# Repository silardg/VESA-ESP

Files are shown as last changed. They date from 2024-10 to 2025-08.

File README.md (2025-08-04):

# VESA-Mountable ESP32-S3 with VGA Output

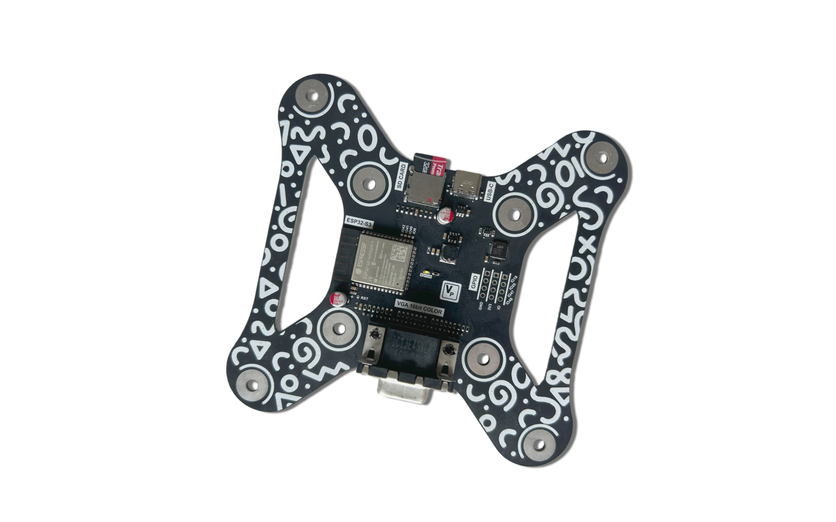
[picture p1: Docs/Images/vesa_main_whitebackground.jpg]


## Overview

This project is a **VESA-mountable ESP32-S3** development board with **VGA output** — a unique and space-saving solution for embedded applications that benefit from graphical displays.

The core idea is simple: create a **microcontroller-based VGA device** that can be easily attached to the back of a monitor using a **VESA-compatible plate PCB**. This results in a clutter-free and elegant hardware setup, ideal for DIYers, educators, and tinkerers.

## Why It’s Cool

- **VGA from a microcontroller**: VGA video from the ESP32-S3 is no small feat.
- **Compact design**: Mounts directly behind your monitor using standard VESA mounting holes.
- **Open Hardware**: Schematics and PCB designs are fully available.

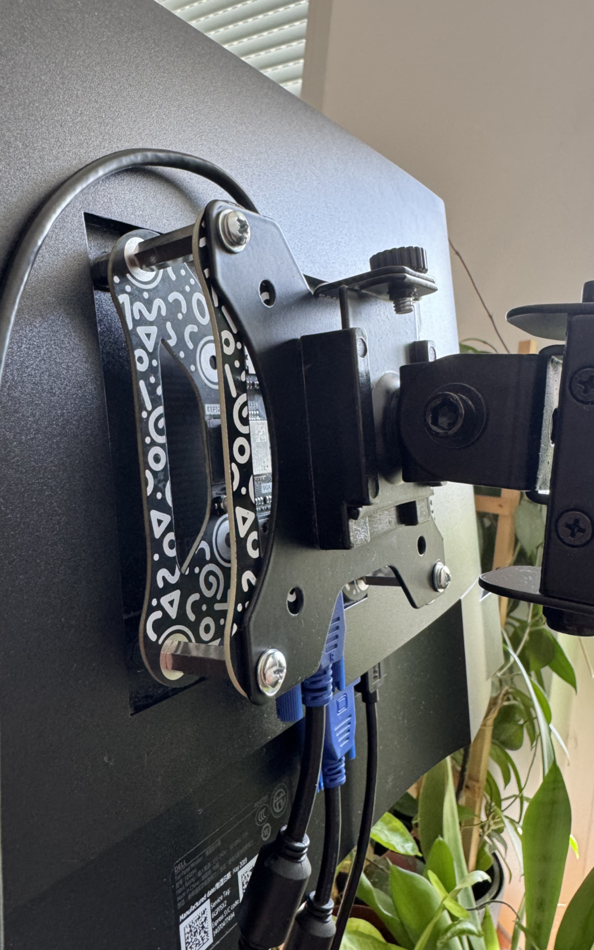
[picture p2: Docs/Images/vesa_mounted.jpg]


## Shoutout

This project wouldn’t be possible without the incredible work of **[BitLuni](https://github.com/bitluni)**, who developed the groundbreaking library that enables VGA output on the ESP32-S3.

## Project Files

The GitHub repository contains:

- ✅ Schematic files  
- ✅ PCB layout files  
- ✅ Firmware

## Documentation
The documentation can be found [here](Docs/DOC.md).

## Mechanical 
Link to the mechanical files can be found [here](Hardware/Main/Manufacturing/Assembly/Dimensions.pdf).

## Certification
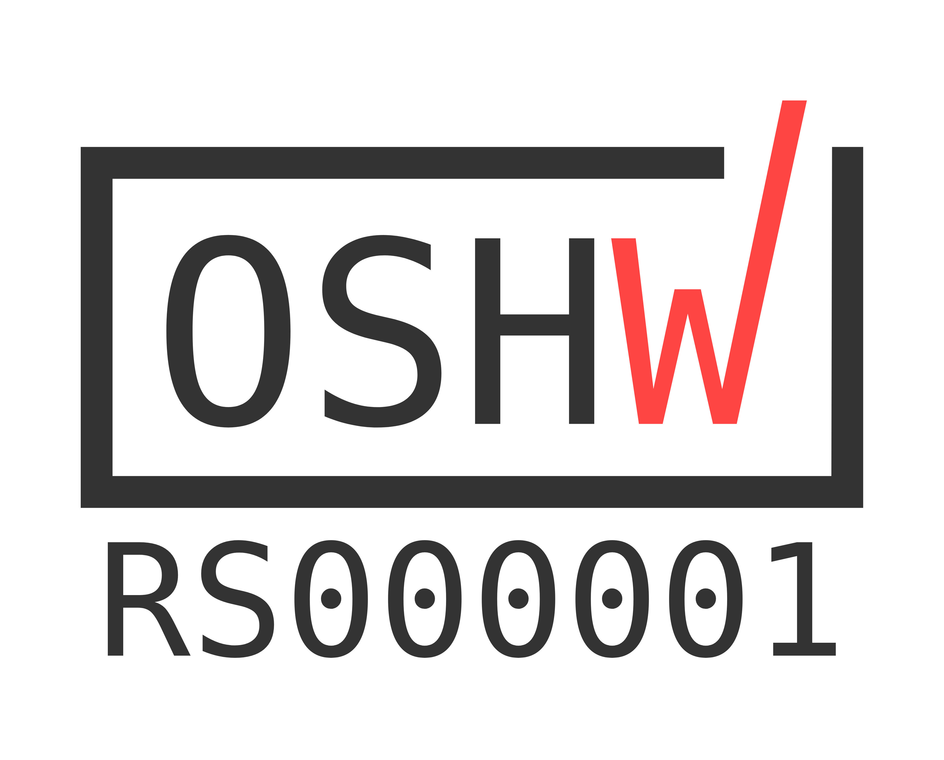
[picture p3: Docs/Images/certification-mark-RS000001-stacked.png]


You can view more [here](https://certification.oshwa.org/rs000001.html) about the certification. P.S. First OSHWA in Serbia!

## Media Coverage
- 🔗 [Official WebPage](https://silardgal.com/projects/vesaesp.html)
- 🔗 [LinkedIn Post](https://www.linkedin.com/posts/silard-gal_hobby-project-finally-finished-this-activity-7321973185086722048-SGIh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)
- 🔗 [Hackaday.io Project Page](https://hackaday.io/project/203136-vesa-esp)
- 🔗 [Hackster.io — Gareth Halfacree’s writeup](https://www.hackster.io/news/silard-gal-s-vesa-esp-puts-an-espressif-esp32-s3-on-the-back-of-any-vesa-compatible-display-0b7a13a0985f)
- More coverage coming soon!

## Licenses


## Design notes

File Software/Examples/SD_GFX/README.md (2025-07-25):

# SD_GFX.ino

## Overview
This Arduino sketch combines SD card access with VGA display output on an ESP32-S3 microcontroller using the VESA-ESP. It lists the contents of an SD card on both the Serial Monitor and a VGA display using the `ESP32S3VGA` and `Adafruit_GFX` libraries.

## Functionality
- **SPI Setup**: Configures a custom SPI interface for SD card communication using defined pins for MOSI, MISO, SCK, and CS.
- **SD Card Initialization**: Initializes the SD card using the `SD` library.
- **Display Setup**: Initializes a VGA display in 320x240 resolution at 60Hz using the `ESP32S3VGA` library.
- **Directory Listing**: Recursively lists all files and directories on the SD card, printing their names to the Serial Monitor and displaying them on the VGA screen with a 200ms delay between each entry.
- **Static Operation**: The listing occurs once during setup, with no actions in the loop.

## Required Libraries
- **ESP32S3VGA**: Provides VGA output functionality for the ESP32-S3.
- **Adafruit_GFX**: A graphics library used via `GfxWrapper` for rendering text and shapes.
- **Adafruit_BusIO** (dependency for Adafruit_GFX): Handles I2C/SPI communication.
- **SD**: Standard Arduino library for SD card operations.
- **SPI**: Standard Arduino library for SPI communication.

## Library Installation
1. Open the Arduino IDE.
2. Go to **Sketch > Include Library > Manage Libraries**.
3. Search for and install:
   - **Adafruit_GFX** (installs Adafruit_BusIO automatically).
   - **SD** and **SPI** (typically included with the Arduino core for ESP32).
4. For **ESP32S3VGA**, refer to the main README for detailed installation instructions, as it may require downloading from an external repository (e.g., GitHub, if provided by the author, such as bitluni) and placing it in the Arduino `libraries` directory or adding it as a `.zip` file.
5. Restart the Arduino IDE after installation.

## Notes
- A VGA connection is needed for the VESA-ESP to display the output.

## Usage
1. Connect an SD card module and ensure the VESA-ESP is connected to a VGA monitor.
2. Insert an SD card formatted with a FAT32 or exFAT file system.
3. Upload the sketch to the ESP32-S3 using the Arduino IDE.
4. Open the Serial Monitor (115200 baud) to view the SD card's directory listing.
5. The VGA monitor will display each file/directory name with a 200ms delay between entries.

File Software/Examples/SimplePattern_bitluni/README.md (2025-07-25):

# SimplePattern_bitluni.ino

## Overview
This Arduino sketch demonstrates a simple VGA display pattern for the ESP32-S3 microcontroller using the VESA-ESP. It generates a colorful test pattern on a VGA monitor using the `ESP32S3VGA` library.

## Functionality
- **Display Setup**: Initializes a VGA display in 800x600 resolution at 60Hz (with an option for 1024x768 commented out).
- **Pattern Generation**: Creates a gradient pattern across the screen where pixel colors are based on their x and y coordinates.
- **Color Bars**: Draws three horizontal color bars (red, green, blue) at the top of the screen, each 30 pixels high, with intensity varying from 0 to 255.
- **Static Display**: The pattern is rendered once and displayed continuously.

## Required Libraries
- **ESP32S3VGA**: Provides VGA output functionality for the ESP32-S3.

## Library Installation
1. Open the Arduino IDE.
2. For **ESP32S3VGA**, refer to the main README for detailed installation instructions, as it may require downloading from an external repository (e.g., GitHub, if provided by the author, such as bitluni) and placing it in the Arduino `libraries` directory or adding it as a `.zip` file.
3. Restart the Arduino IDE after installation.

## Notes
- A VGA connection is needed for the VESA-ESP to display the output.

## Usage
1. Ensure the VESA-ESP is connected to a VGA monitor.
2. Upload the sketch to the ESP32-S3 using the Arduino IDE.
3. The VGA monitor will display the gradient pattern and color bars.

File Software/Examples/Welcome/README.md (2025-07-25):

# Welcome.ino

## Overview
This Arduino sketch is designed for the ESP32-S3 microcontroller to display a thank-you message and a QR code on a VGA monitor using the VESA-ESP. It uses the `ESP32S3VGA` library to interface with a VGA display and the `GfxWrapper` library to render text and graphics.

## Functionality
- **Display Setup**: Initializes a VGA display in 320x240 resolution at 60Hz using the `ESP32S3VGA` library.
- **Text Rendering**: Displays the text "Thank you!" and "For supporting this project! More on:" using the `FreeSerif24pt7b` font.
- **QR Code Rendering**: Renders a 100x100 pixel QR code from a predefined `qr_map` array, where each pixel is either black (1) or white (0).
- **Continuous Display**: The display is updated once and then holds indefinitely with a 500ms delay loop.

## Required Libraries
- **ESP32S3VGA**: Provides VGA output functionality for the ESP32-S3.
- **Adafruit_GFX**: A graphics library used via `GfxWrapper` for rendering text and shapes.
- **Adafruit_BusIO** (dependency for Adafruit_GFX): Handles I2C/SPI communication.

## Library Installation
1. Open the Arduino IDE.
2. Go to **Sketch > Include Library > Manage Libraries**.
3. Search for and install:
   - **Adafruit_GFX** (installs Adafruit_BusIO automatically).
4. For **ESP32S3VGA**, refer to the main README for detailed installation instructions, as it may require downloading from an external repository (e.g., GitHub, if provided by the author, such as bitluni) and placing it in the Arduino `libraries` directory or adding it as a `.zip` file.
5. Restart the Arduino IDE after installation.

## Notes
- A VGA connection is needed for the VESA-ESP to display the output.

## Usage
1. Ensure the VESA-ESP is connected to a VGA monitor.
2. Upload the sketch to the ESP32-S3 using the Arduino IDE.
3. The VGA monitor will display the thank-you message and QR code.

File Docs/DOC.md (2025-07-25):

# VESA-ESP Documentation
## Hardware
### Links
The *SCHEMATIC* can be found [here](../Hardware/Main/Manufacturing/Assembly/VESA-ESP%20([No%20Variations])%20Schematic.PDF).

The *ASSEMBLY* can be found [here](../Hardware/Main/Manufacturing/Assembly/VESA-ESP%20([No%20Variations])%20Assembly%20Drawing.PDF).

The *3D VIEW* can be found [here](../Hardware/Main/Manufacturing/Assembly/VESA-ESP%20([No%20Variations])%20PCB%203D%20Printout.PDF).

### Block Diagram
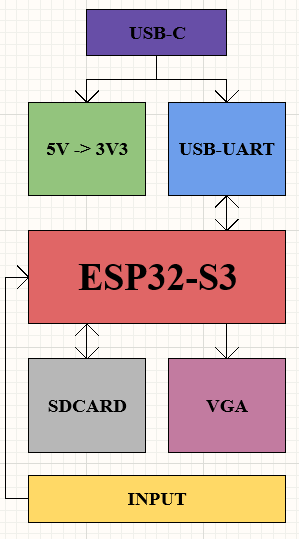
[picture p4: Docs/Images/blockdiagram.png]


### Main Parts
- ESP32-S3
- USB-UART
- VGA Connector
- USB-C and Power
- Inputs
- SD Card

### How to use it and install it?
- Step #1 VGA: Connect a VGA cable to a VGA compatible monitor/tv
- Step #2 Power: USB-C, 5V
- Step #3 Greeted by welcome message (in case the device was sourced from us, if not, follow the below instructions to flash it)
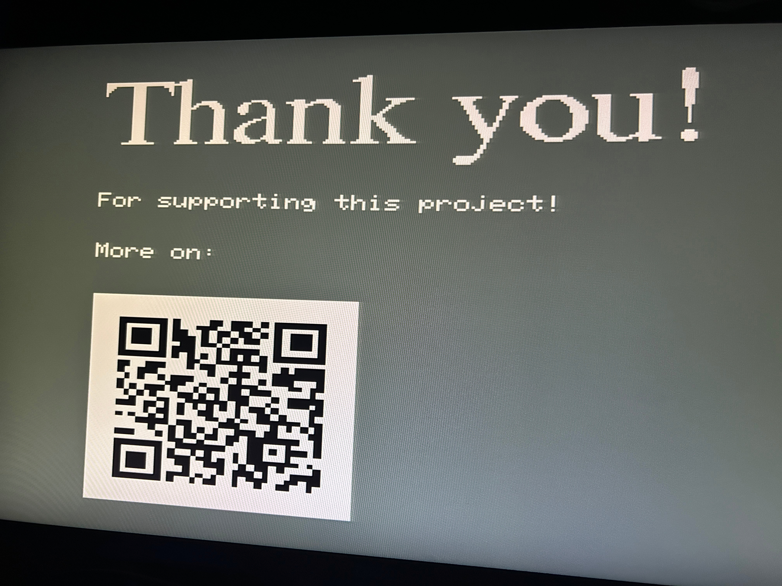
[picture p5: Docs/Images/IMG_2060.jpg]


The device is made so that it can be mounted on the back of monitors using the two groups of screws.
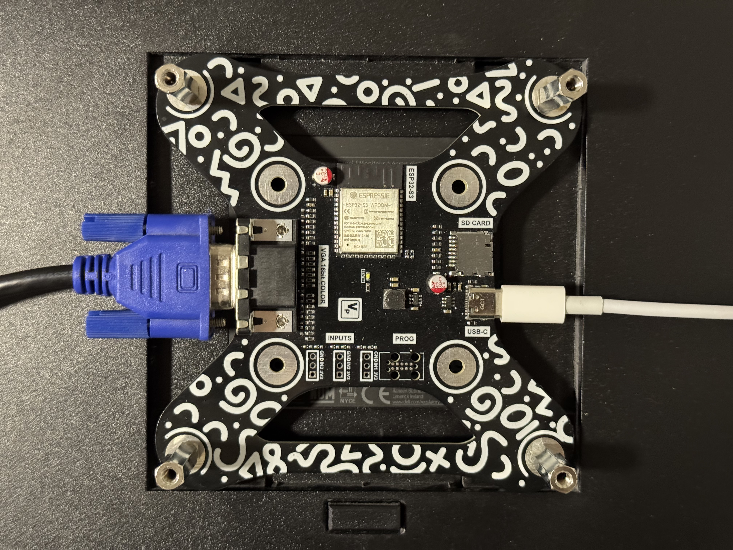
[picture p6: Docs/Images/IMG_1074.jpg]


The additional adapter plate is there to allow using stands with the device. 
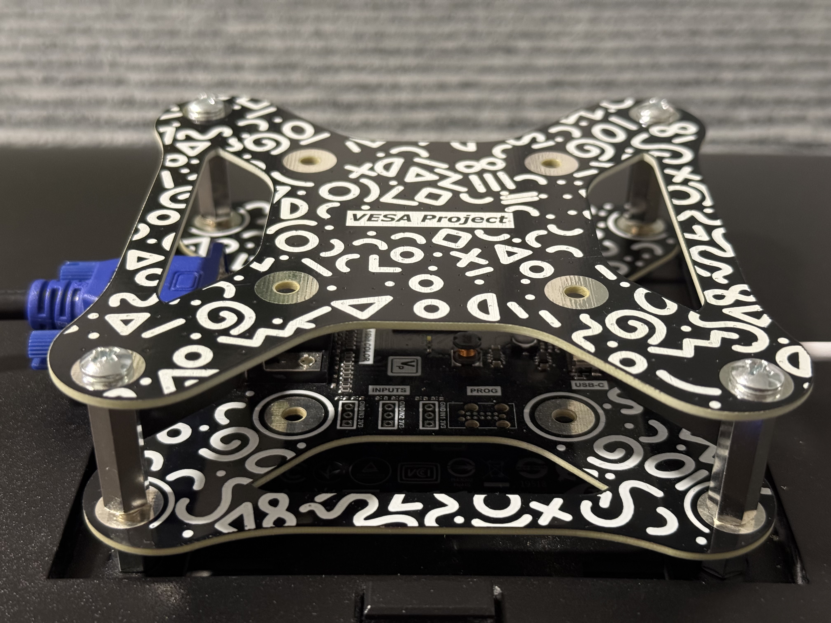
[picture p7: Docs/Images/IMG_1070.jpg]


## Software/Firmware
### Setup the software
- Step #1 Install Arduino: [Install the Arduino IDE](https://www.arduino.cc/en/software/)
- Step #2 Install ESP32: Add https://dl.espressif.com/dl/package_esp32_index.json to the Boards Manager URL in the Preferences ( File -> Preferences)
- Step #3 Install bitluni library: [Intro here](https://github.com/bitluni/ESP32Lib)
- Step #4 Run bitluni or our Examples!
### VGA Output
The VGA output is the main purpose of this device, meaning all examples are using it!

The device should come with a pre-loaded firmware that will showcase some text, thanking for support and a QR code leading to this webpage.

In the [Software/Examples](../Software/Examples/) section there are many examples to get started from. 
### SD Card Interfacing
The example [SD_Test](../Software/Examples/SD_Test/) and [SD_GFX](../Software/Examples/SD_GFX/) is used to showcase the SD Card. 

As shown on the schematic, only 1-bit mode is used to interface the SD-Card, because of the limitation of the ESP32 with OPI PSRAM.
### GPIO interfacing
IO19, IO20, IO47 and IO48 can be used as separate IO on the connector. 

### Licenses


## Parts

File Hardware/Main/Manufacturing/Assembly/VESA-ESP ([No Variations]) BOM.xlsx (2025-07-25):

Name | Description | Designator | LibRef | Quantity | Layer | MPN
3.9uH/3.6A | FIXED IND 3.9UH 3.6A 65 MOHM SMD | L1 | 3.9uH/3.6A | 1 | Top | SDE0604A-3R9M
5K1 1% | 5.1 kOhms ±1% 0.1W, 1/10W Chip Resistor 0603 (1608 Metric) Automotive AEC-Q200 Thick Film | R1, R2 | 5K1 1% | 2 | Top | ERJ-3EKF5101V
22uF 6V3 | 22 µF ±20% 6.3V Ceramic Capacitor X5R 0603 (1608 Metric) | C2, C5, C6, C7, C10 | 22uF 6V3 | 5 | Top | GRM188R60J226MEA0D
150R 1% | 150 Ohms ±1% 0.1W, 1/10W Chip Resistor 0603 (1608 Metric) Automotive AEC-Q200 Thick Film | R9, R10, R11, R12, R14, R22, R23, R24, R25, R33, R34, R35, R36, R38, R46 | 150R 1% | 15 | Top | ERJ-3EKF1500V
300R 1% | 300 Ohms ±1% 0.1W, 1/10W Chip Resistor 0603 (1608 Metric) Automotive AEC-Q200 Thick Film | R3, R4, R5, R6, R7, R13, R16, R17, R18, R19, R20, R26, R27, R28, R29, R30, R31, R32, R37, R47, R54 | 300R 1% | 21 | Top | ERJ-3EKF3000V
AP63203WU-7 | Buck Switching Regulator IC Positive Fixed 3.3V 1 Output 2A SOT-23-6 Thin, TSOT-23-6 | U2 | AP63203WU-7 | 1 | Top | AP63203WU-7
BC847BS-7-F | Bipolar (BJT) Transistor Array 2 NPN (Dual) 45V 100mA 100MHz 200mW Surface Mount SOT-363 | Q1 | BC847BS-7-F | 1 | Top | BC847BS-7-F
CP2102N-A02-GQFN28 | USB Bridge, USB to UART USB 2.0 UART Interface 28-QFN (5x5) | U4 | CP2102N-A02-GQFN28 | 1 | Top | CP2102N-A02-GQFN28
DM3D-SF | 10 (8 + 2) Position Card Connector Secure Digital - microSD™ Surface Mount, Right Angle Gold | J3 | DM3D-SF | 1 | Top | DM3D-SF
ESP32-S3-WROOM-1-N16R8 | Bluetooth, WiFi 802.11b/g/n, Bluetooth v5.0 Transceiver Module 2.4GHz PCB Trace Surface Mount | U1 | ESP32-S3-WROOM-1-N16R8 | 1 | Top | ESP32-S3-WROOM-1-N16R8
ICD15S13E4GX00LF | 15 Position D-Sub, High Density Receptacle, Female Sockets Connector | J2 | ICD15S13E4GX00LF | 1 | Top | ICD15S13E4GX00LF
QBLP601-IW | White LED Indication - Discrete 3.2V 0603 (1608 Metric) | D1 | LED WHITE | 1 | Top | QBLP601-IW
USB4105-GF-A | USB-C (USB TYPE-C) USB 2.0 Receptacle Connector 24 (16+8 Dummy) Position Surface Mount, Right Angle; Through Hole | J1 | USB4105-GF-A | 1 | Top | USB4105-GF-A
USBLC6-2SC6 | 17V Clamp 5A (8/20µs) Ipp Tvs Diode Surface Mount SOT-23-6 | U3 | USBLC6-2SC6 | 1 | Top | USBLC6-2SC6
47uF 20V | 47 µF 16 V Aluminum Electrolytic Capacitors Radial, Can - SMD 2000 Hrs @ 105°C | C4, C9 | 47uF 20V | 2 | Top | [NoParam], 865080342006
10K 1% | 10 kOhms ±1% 0.1W, 1/10W Chip Resistor 0603 (1608 Metric) Automotive AEC-Q200 Thick Film | R8, R39, R40, R41, R42, R43, R44, R45, R51, R52, R53, R60 | 10K 1% | 12 | Top | ERJ-3EKF1002V
100nF 50V | 0.1 µF ±10% 50V Ceramic Capacitor X7R 0603 (1608 Metric) | C1, C3, C8, C11, C12, C13 | 100nF 50V | 6 | Top | GCM188R71H104KA57D

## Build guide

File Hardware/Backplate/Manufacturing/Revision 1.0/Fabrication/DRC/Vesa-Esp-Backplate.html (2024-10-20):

Altium

# Design Rule Verification Report

Date: | | 10/20/2024
Time: | | 15:55:22
Elapsed Time: | | 00:00:01
Filename: | | C:\Users\Silard Gal\AppData\Local\Temp\Releases\Snapshot\3\Pcb\Vesa-Esp-Backplate.PcbDoc

Warnings: | | 0
Rule Violations: | | 0

## Summary

Warnings | Count
Total | 0

Rule Violations | Count
Clearance Constraint (Gap=0.127mm) (All),(All) | 0
Short-Circuit Constraint (Allowed=No) (All),(All) | 0
Un-Routed Net Constraint ( (All) ) | 0
Modified Polygon (Allow modified: No), (Allow shelved: No) | 0
Width Constraint (Min=0.254mm) (Max=25.4mm) (Preferred=0.254mm) (All) | 0
Width Constraint (Min=0.152mm) (Max=25.4mm) (Preferred=0.152mm) (All) | 0
Width Constraint (Min=0.127mm) (Max=25.4mm) (Preferred=0.127mm) (All) | 0
Width Constraint (Min=0.508mm) (Max=25.4mm) (Preferred=0.508mm) (All) | 0
Width Constraint (Min=0.305mm) (Max=25.4mm) (Preferred=0.305mm) (All) | 0
Power Plane Connect Rule(Direct Connect )(Expansion=0.508mm) (Conductor Width=0.254mm) (Air Gap=0.254mm) (Entries=4) (InPadClass('PowerPads')) | 0
Power Plane Connect Rule(Relief Connect )(Expansion=0.3mm) (Conductor Width=0.127mm) (Air Gap=0.127mm) (Entries=4) (All) | 0
Minimum Annular Ring (Minimum=0.152mm) (All) | 0
Hole Size Constraint (Min=0.3mm) (Max=6.3mm) (All) | 0
Hole To Hole Clearance (Gap=0.254mm) (All),(All) | 0
Minimum Solder Mask Sliver (Gap=0.152mm) (All),(All) | 0
Silk To Solder Mask (Clearance=0.127mm) (IsPad),(All) | 0
Silk to Silk (Clearance=0.127mm) (All),(All) | 0
Net Antennae (Tolerance=0mm) (All) | 0
Board Clearance Constraint (Gap=0mm) (All) | 0
Height Constraint (Min=0mm) (Max=1816.048mm) (Prefered=12.7mm) (All) | 0
Total | 0

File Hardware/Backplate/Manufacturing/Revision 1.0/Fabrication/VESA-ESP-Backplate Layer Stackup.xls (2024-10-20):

Board Stack Report
Stack Up |  | Layer Stack
Layer | Board Layer Stack | Name | Material | Thickness | Constant
1 |  | Top Paste
2 |  | Top Overlay
3 |  | Top Solder | Solder Resist | 0.010mm | 3.5
4 |  | Top Layer | Copper | 0.036mm
5 |  | Dielectric 1 | FR-4 | 0.320mm | 4.8
6 |  | Bottom Layer | Copper | 0.036mm
7 |  | Bottom Solder | Solder Resist | 0.010mm | 3.5
8 |  | Bottom Overlay
9 |  | Bottom Paste
 | Height : 0.411mm

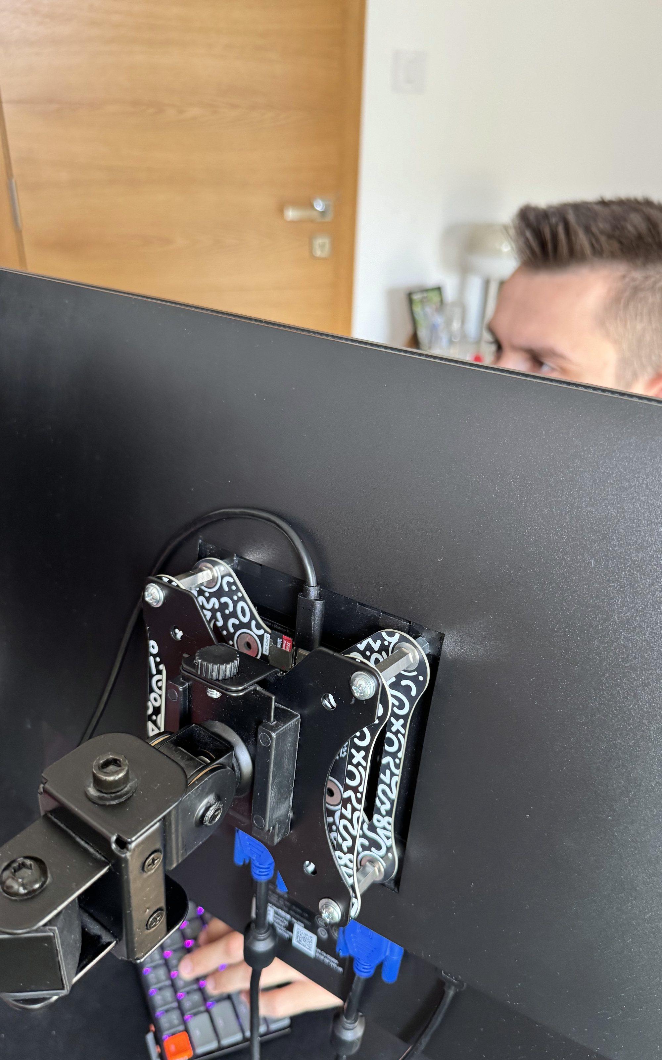
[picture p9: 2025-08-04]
Docs/Images/vesa_usage.jpg

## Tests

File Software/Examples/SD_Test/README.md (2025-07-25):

# SD_Test.ino

## Overview
This Arduino sketch tests the functionality of an SD card connected to an ESP32-S3 microcontroller using a custom SPI interface. It lists the contents of the SD card on the Serial Monitor.

## Functionality
- **SPI Setup**: Configures a custom SPI interface using defined pins for MOSI, MISO, SCK, and CS.
- **SD Card Initialization**: Initializes the SD card using the `SD` library over the custom SPI interface.
- **Directory Listing**: Recursively lists all files and directories on the SD card, printing their names and sizes (for files) to the Serial Monitor.
- **Static Operation**: The listing occurs once during setup, with no actions in the loop.

## Required Libraries
- **SD**: Standard Arduino library for SD card operations.
- **SPI**: Standard Arduino library for SPI communication.

## Library Installation
1. Open the Arduino IDE.
2. The **SD** and **SPI** libraries are included with the Arduino core for ESP32, so no additional installation is typically required.
3. If not present, go to **Sketch > Include Library > Manage Libraries** and search for **SD** and **SPI** to ensure they are installed.
4. Restart the Arduino IDE if any libraries are installed.

## Notes
- No VGA connection is required for this sketch, as it outputs to the Serial Monitor.

## Usage
1. Connect an SD card module to the ESP32-S3 using the specified SPI pins.
2. Insert an SD card formatted with a FAT32 or exFAT file system.
3. Upload the sketch to the ESP32-S3 using the Arduino IDE.
4. Open the Serial Monitor (115200 baud) to view the SD card's directory listing.

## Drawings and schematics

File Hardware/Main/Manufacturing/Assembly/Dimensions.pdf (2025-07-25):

AA

BB

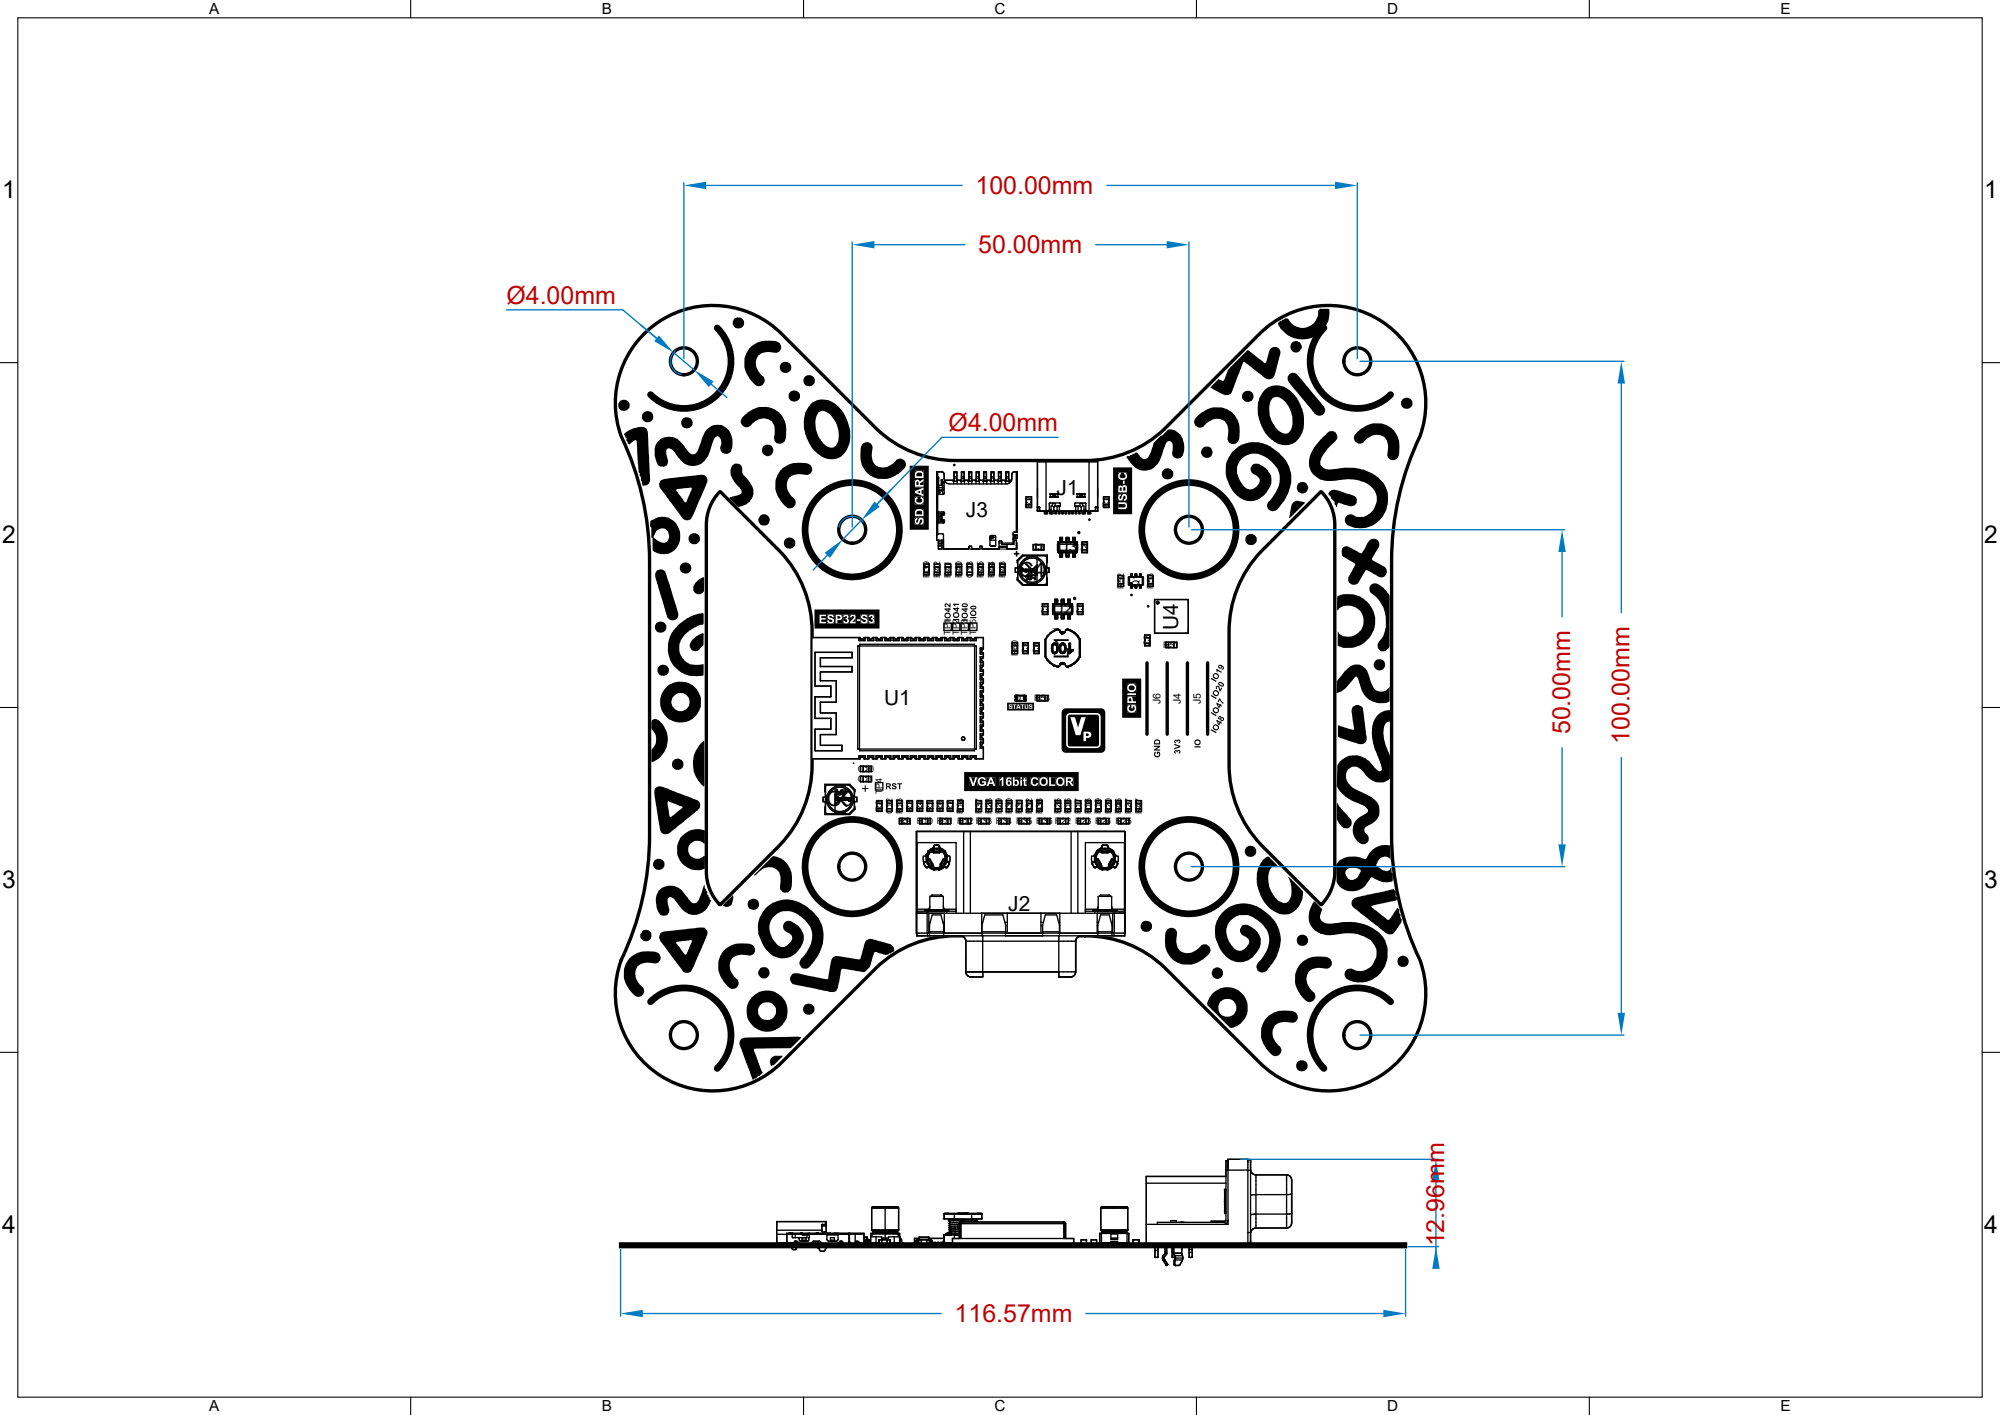
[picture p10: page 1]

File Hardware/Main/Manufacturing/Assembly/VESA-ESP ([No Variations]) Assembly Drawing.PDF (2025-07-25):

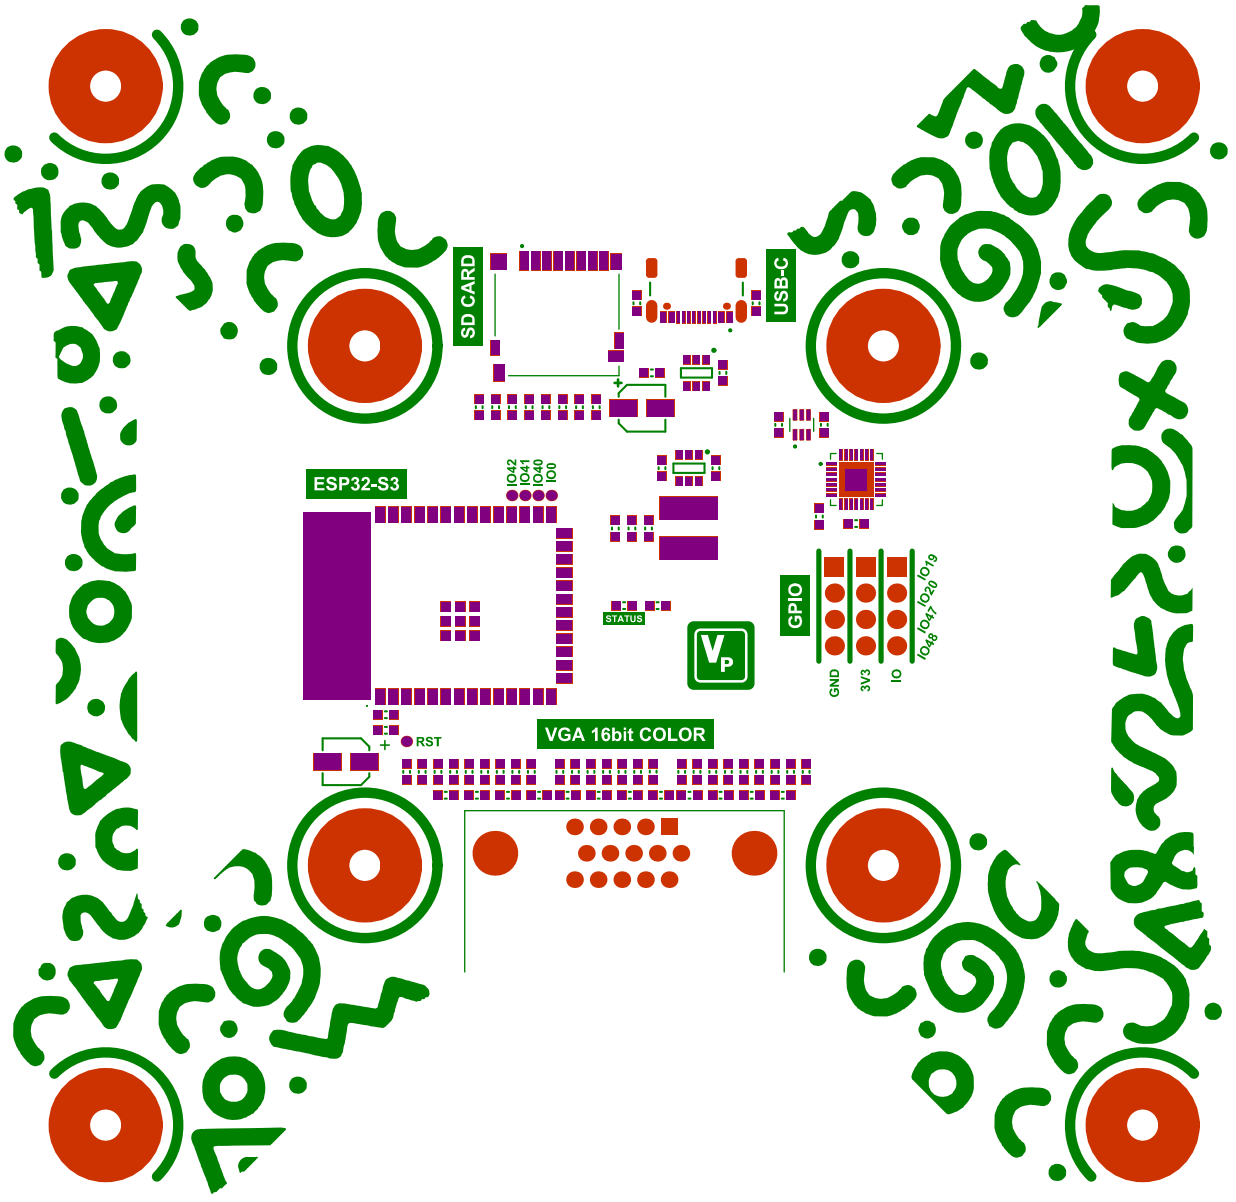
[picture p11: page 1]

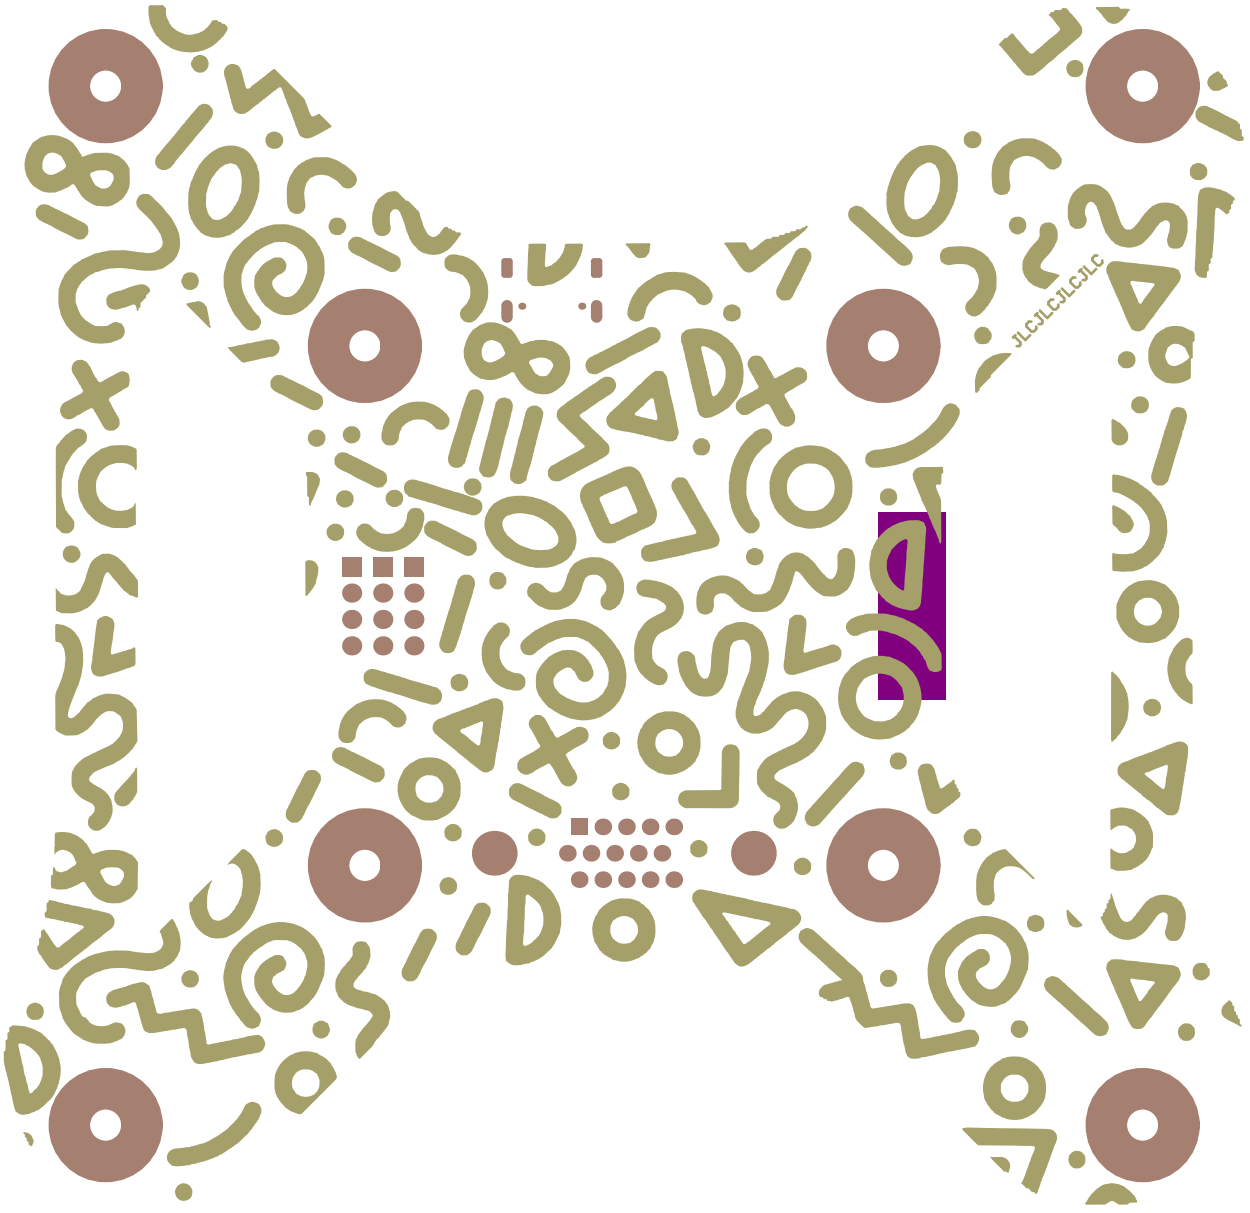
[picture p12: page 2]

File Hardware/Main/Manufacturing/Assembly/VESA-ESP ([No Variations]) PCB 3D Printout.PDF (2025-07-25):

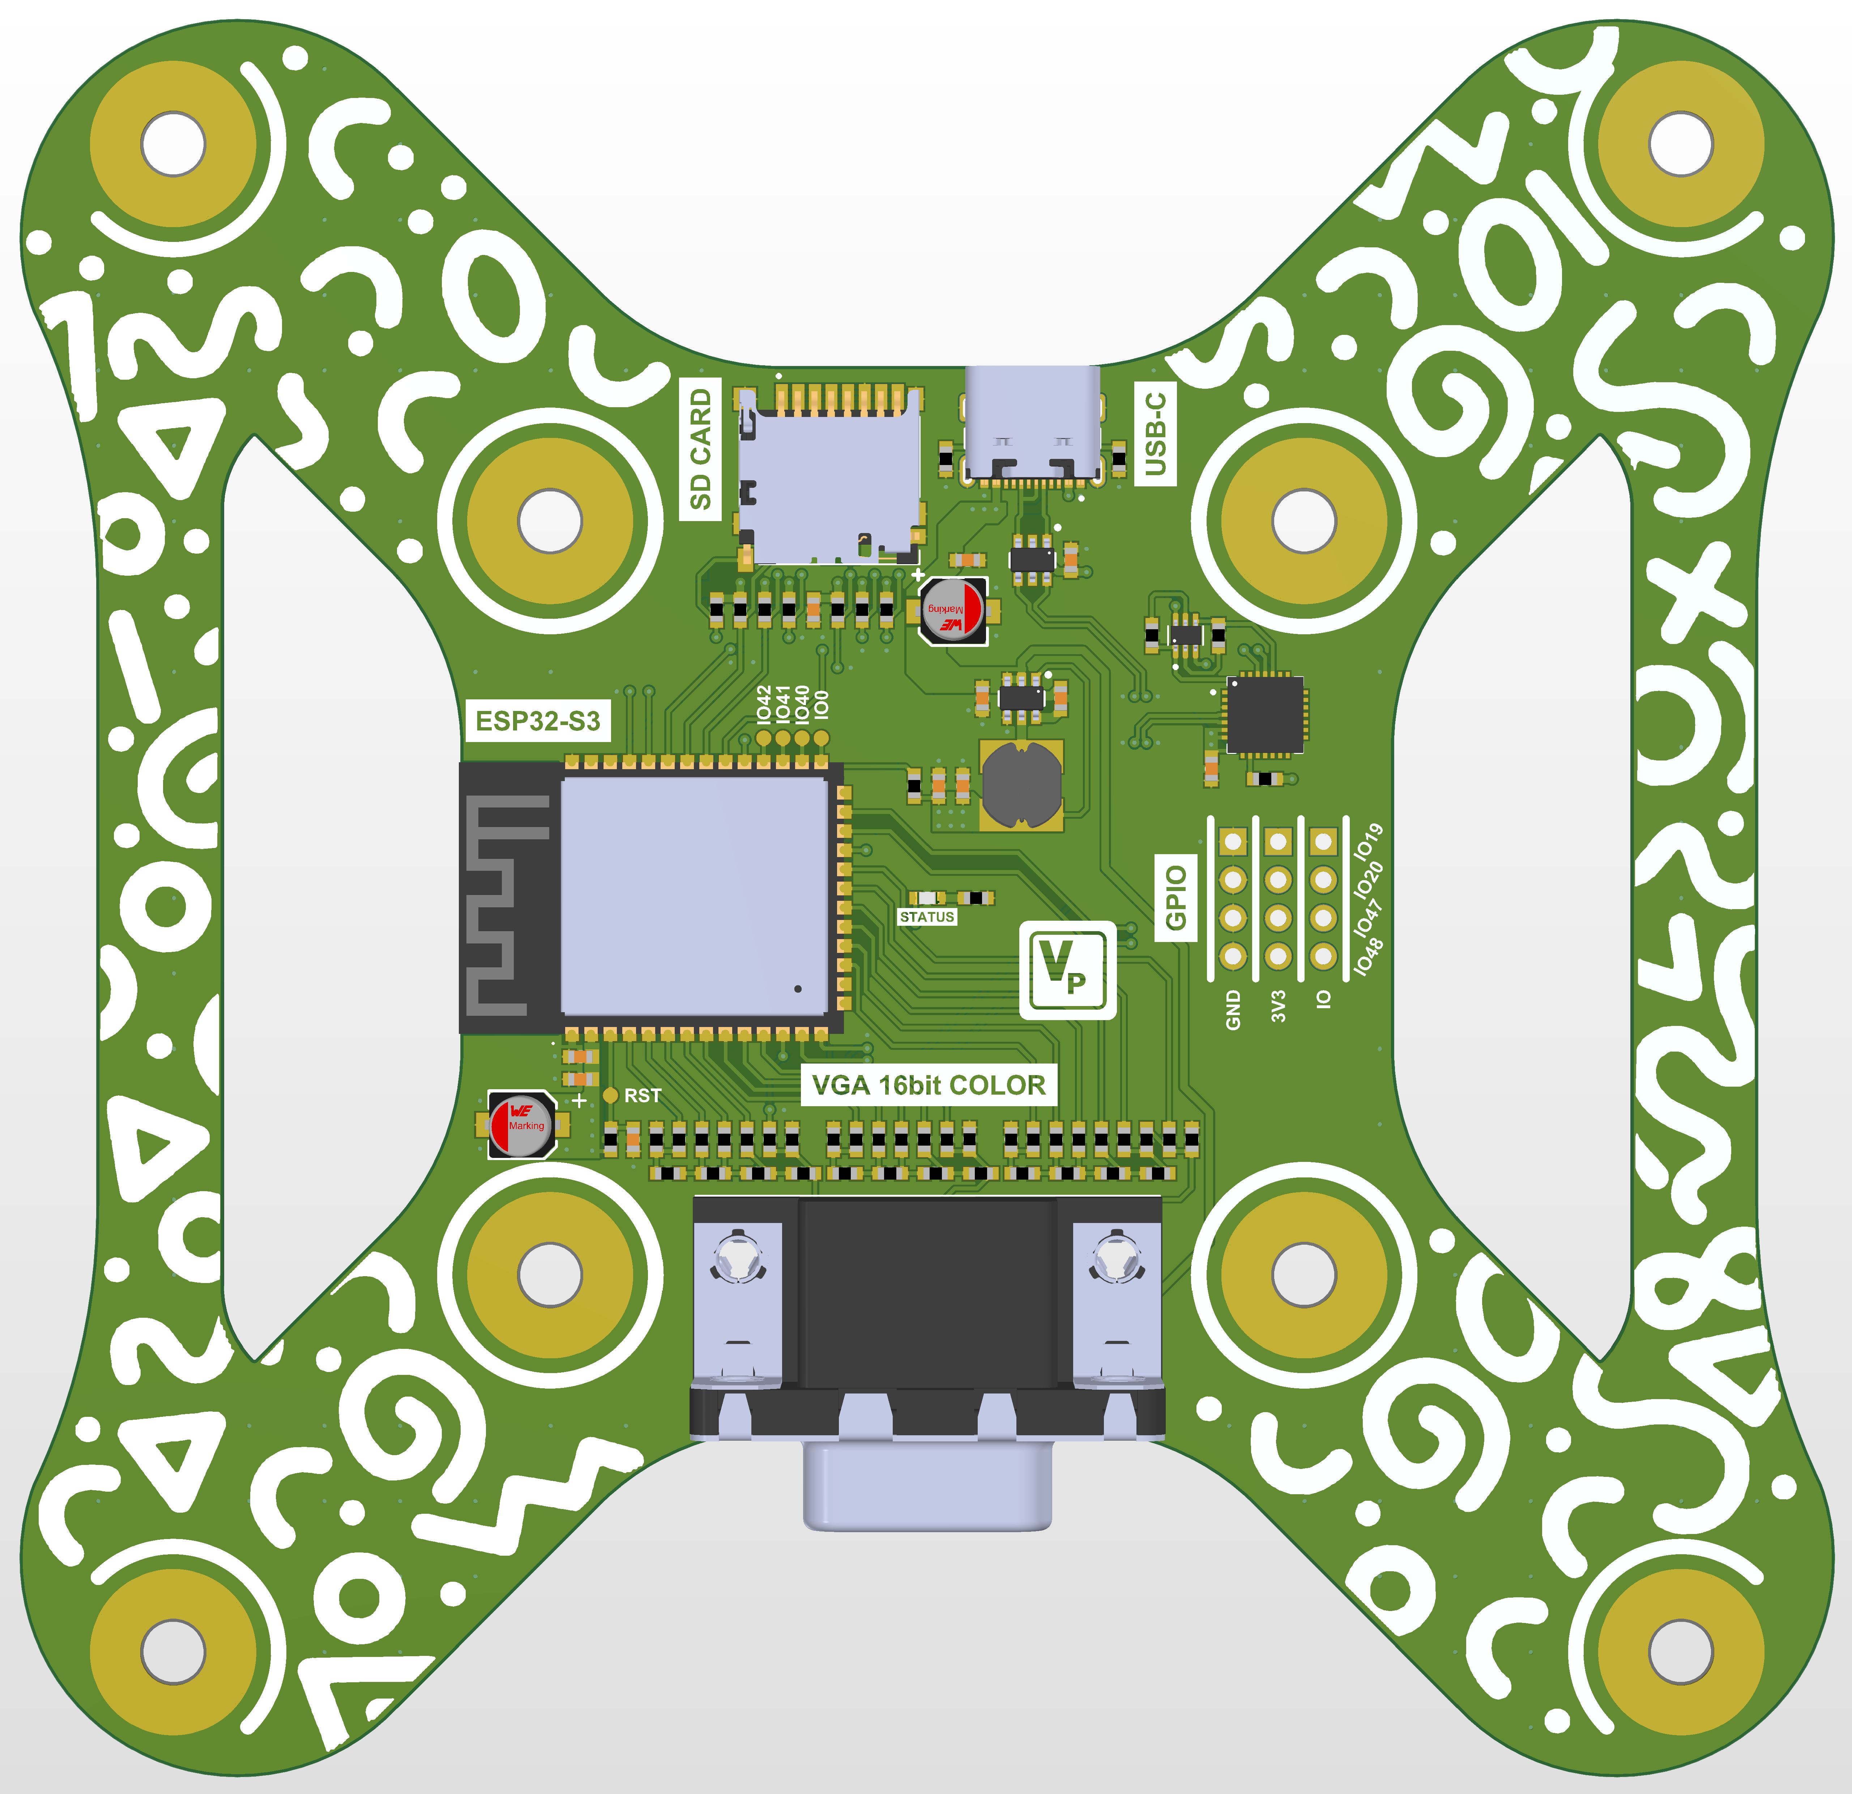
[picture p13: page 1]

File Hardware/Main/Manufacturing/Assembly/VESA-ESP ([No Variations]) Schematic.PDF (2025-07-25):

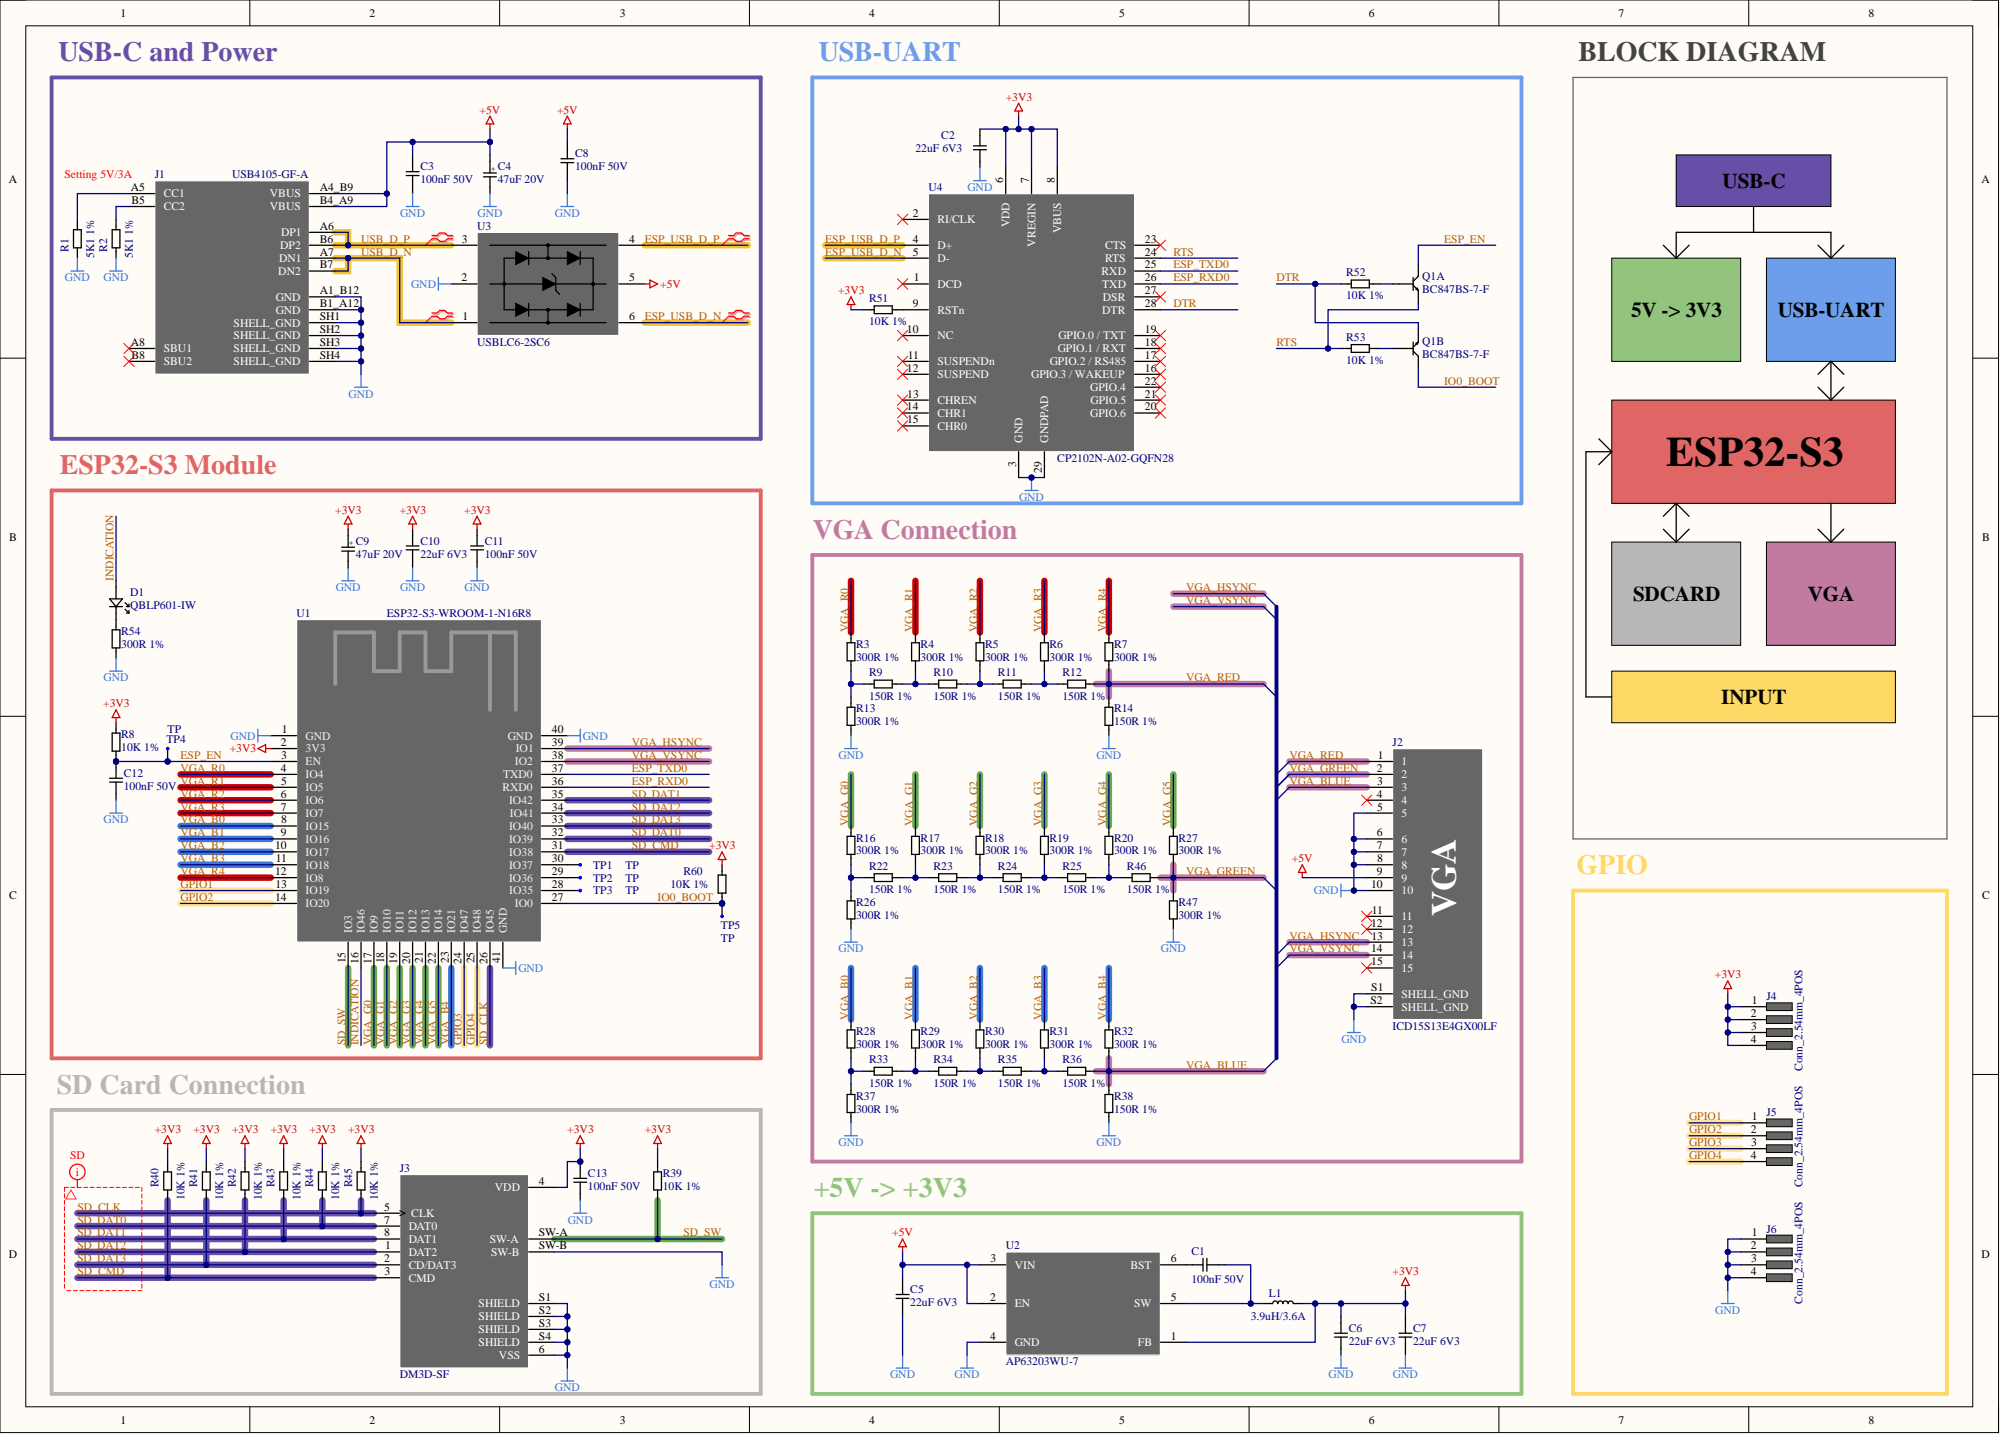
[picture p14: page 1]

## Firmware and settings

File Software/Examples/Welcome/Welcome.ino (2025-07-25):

#include "ESP32S3VGA.h"
#include <GfxWrapper.h>
#include <Fonts/FreeMonoBoldOblique24pt7b.h>
#include <Fonts/FreeSerif24pt7b.h>

const uint8_t qr_map[100 * 100] = {
  0, 0, 0, 0, 0, 0, 0, 0, 0, 0, 0, 0, 0, 0, 0, 0, 0, 0, 0, 0, 0, 0, 0, 0, 0,
  0, 0, 0, 0, 0, 0, 0, 0, 0, 0, 0, 0, 0, 0, 0, 0, 0, 0, 0, 0, 0, 0, 0, 0, 0,
  0, 0, 0, 0, 0, 0, 0, 0, 0, 0, 0, 0, 0, 0, 0, 0, 0, 0, 0, 0, 0, 0, 0, 0, 0,
  0, 0, 0, 0, 0, 0, 0, 0, 0, 0, 0, 0, 0, 0, 0, 0, 0, 0, 0, 0, 0, 0, 0, 0, 0,
  0, 0, 0, 0, 0, 0, 0, 0, 0, 0, 0, 0, 0, 0, 0, 0, 0, 0, 0, 0, 0, 0, 0, 0, 0,
  0, 0, 0, 0, 0, 0, 0, 0, 0, 0, 0, 0, 0, 0, 0, 0, 0, 0, 0, 0, 0, 0, 0, 0, 0,
  0, 0, 0, 0, 0, 0, 0, 0, 0, 0, 0, 0, 0, 0, 0, 0, 0, 0, 0, 0, 0, 0, 0, 0, 0,
  0, 0, 0, 0, 0, 0, 0, 0, 0, 0, 0, 0, 0, 0, 0, 0, 0, 0, 0, 0, 0, 0, 0, 0, 0,
  0, 0, 0, 0, 0, 0, 0, 0, 0, 0, 0, 0, 0, 0, 0, 0, 0, 0, 0, 0, 0, 0, 0, 0, 0,
  0, 0, 0, 0, 0, 0, 0, 0, 0, 0, 0, 0, 0, 0, 0, 0, 0, 0, 0, 0, 0, 0, 0, 0, 0,
  0, 0, 0, 0, 0, 0, 0, 0, 0, 0, 0, 0, 0, 0, 0, 0, 0, 0, 0, 0, 0, 0, 0, 0, 0,
  0, 0, 0, 0, 0, 0, 0, 0, 0, 0, 0, 0, 0, 0, 0, 0, 0, 0, 0, 0, 0, 0, 0, 0, 0,
  0, 0, 0, 0, 0, 0, 0, 0, 0, 0, 0, 0, 0, 0, 0, 0, 0, 0, 0, 0, 0, 0, 0, 0, 0,
  0, 0, 0, 0, 0, 0, 0, 0, 0, 0, 0, 0, 0, 0, 0, 0, 0, 0, 0, 0, 0, 0, 0, 0, 0,
  0, 0, 0, 0, 0, 0, 0, 0, 0, 0, 0, 0, 0, 0, 0, 0, 0, 0, 0, 0, 0, 0, 0, 0, 0,
  0, 0, 0, 0, 0, 0, 0, 0, 0, 0, 0, 0, 0, 0, 0, 0, 0, 0, 0, 0, 0, 0, 0, 0, 0,
  0, 0, 0, 0, 0, 0, 0, 0, 0, 0, 0, 0, 0, 0, 0, 0, 0, 0, 0, 0, 0, 0, 0, 0, 0,
  0, 0, 0, 0, 0, 0, 0, 0, 0, 0, 0, 0, 0, 0, 0, 0, 0, 0, 0, 0, 0, 0, 0, 0, 0,
  0, 0, 0, 0, 0, 0, 0, 0, 0, 0, 0, 0, 0, 0, 0, 0, 0, 0, 0, 0, 0, 0, 0, 0, 0,
  0, 0, 0, 0, 0, 0, 0, 0, 0, 0, 0, 0, 0, 0, 0, 0, 0, 0, 0, 0, 0, 0, 0, 0, 0,
  0, 0, 0, 0, 0, 0, 0, 0, 0, 0, 0, 0, 0, 0, 0, 0, 0, 0, 0, 0, 0, 0, 0, 0, 0,
  0, 0, 0, 0, 0, 0, 0, 0, 0, 0, 0, 0, 0, 0, 0, 0, 0, 0, 0, 0, 0, 0, 0, 0, 0,
  0, 0, 0, 0, 0, 0, 0, 0, 0, 0, 0, 0, 0, 0, 0, 0, 0, 0, 0, 0, 0, 0, 0, 0, 0,
  0, 0, 0, 0, 0, 0, 0, 0, 0, 0, 0, 0, 0, 0, 0, 0, 0, 0, 0, 0, 0, 0, 0, 0, 0,
  0, 0, 0, 0, 0, 0, 0, 0, 0, 0, 0, 0, 0, 0, 0, 0, 0, 0, 0, 0, 0, 0, 0, 0, 0,
  0, 0, 0, 0, 0, 0, 0, 0, 0, 0, 0, 0, 0, 0, 0, 0, 0, 0, 0, 0, 0, 0, 0, 0, 0,
  0, 0, 0, 0, 0, 0, 0, 0, 0, 0, 0, 0, 0, 0, 0, 0, 0, 0, 0, 0, 0, 0, 0, 0, 0,
  0, 0, 0, 0, 0, 0, 0, 0, 0, 0, 0, 0, 0, 0, 0, 0, 0, 0, 0, 0, 0, 0, 0, 0, 0,
  0, 0, 0, 0, 0, 0, 0, 0, 0, 0, 0, 0, 0, 0, 0, 0, 0, 0, 0, 0, 0, 0, 0, 0, 0,
  0, 0, 0, 0, 0, 0, 0, 0, 0, 0, 0, 0, 0, 0, 0, 0, 0, 0, 0, 0, 0, 0, 0, 0, 0,
  0, 0, 0, 0, 0, 0, 0, 0, 0, 0, 0, 0, 0, 0, 0, 0, 0, 0, 0, 0, 0, 0, 0, 0, 0,
  0, 0, 0, 0, 0, 0, 0, 0, 0, 0, 0, 0, 0, 0, 0, 0, 0, 0, 0, 0, 0, 0, 0, 0, 0,
  0, 0, 0, 0, 0, 0, 0, 0, 0, 0, 0, 0, 0, 0, 0, 0, 0, 0, 0, 0, 0, 0, 0, 0, 0,
  0, 0, 0, 0, 0, 0, 0, 0, 0, 0, 0, 0, 0, 0, 0, 0, 0, 0, 0, 0, 0, 0, 0, 0, 0,
  0, 0, 0, 0, 0, 0, 0, 0, 0, 0, 0, 0, 0, 0, 0, 0, 0, 0, 0, 0, 0, 0, 0, 0, 0,
  0, 0, 0, 0, 0, 0, 0, 0, 0, 0, 0, 0, 0, 0, 0, 0, 0, 0, 0, 0, 0, 0, 0, 0, 0,
  0, 0, 0, 0, 0, 0, 0, 0, 0, 0, 0, 0, 0, 0, 0, 0, 0, 0, 0, 0, 0, 0, 0, 0, 0,
  0, 0, 0, 0, 0, 0, 0, 0, 0, 0, 0, 0, 0, 0, 0, 0, 0, 0, 0, 0, 0, 0, 0, 0, 0,
  0, 0, 0, 0, 0, 0, 0, 0, 0, 0, 0, 0, 0, 0, 0, 0, 0, 0, 0, 0, 0, 0, 0, 0, 0,
  0, 0, 0, 0, 0, 0, 0, 0, 0, 0, 0, 0, 0, 0, 0, 0, 0, 0, 0, 0, 0, 0, 0, 0, 0,
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
};
//                   r,r,r,r,r,  g,g, g, g, g, g,   b, b, b, b, b,   h,v
const PinConfig pins(4,5,6,7,8,  9,10,11,12,13,14,  15,16,17,18,21,  1,2);

//VGA Device
VGA vga;
Mode mode = Mode::MODE_320x240x60;
GfxWrapper<VGA> gfx(vga, mode.hRes, mode.vRes);

//initial setup
void setup()
{
	vga.bufferCount = 2;
	if(!vga.init(pins, mode, 16)) while(1) delay(1);

	vga.start();
}

//the loop is done every frame
void loop()
{
	static int x = 0;
	vga.clear(vga.rgb(96, 96, 96));
  gfx.setFont(&FreeSerif24pt7b);
  gfx.setCursor(50,50);
  gfx.print("Thank you!");
  gfx.setFont();
  gfx.setCursor(50,75);
  gfx.print("For supporting this project!");
  gfx.setCursor(50,100);
  gfx.print("More on:");
  
  const int scale = 1;
  const int xOffset = 50;
  const int yOffset = 125;

  for (int y = 0; y < 100; y++) {
    for (int x = 0; x < 100; x++) {
      uint8_t pixel = qr_map[y * 100 + x];
      uint16_t color = (pixel == 1) ? vga.rgb(0, 0, 0) : vga.rgb(255, 255, 255);
      gfx.fillRect(xOffset + x * scale, yOffset + y * scale, scale, scale, color);
    }
  }

	vga.show();

  while(1) {
    delay(500);
  }
}

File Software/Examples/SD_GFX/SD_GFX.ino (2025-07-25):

#include <SD.h>
#include <SPI.h>
#include "ESP32S3VGA.h"
#include <GfxWrapper.h>
#include <Fonts/FreeMonoBoldOblique24pt7b.h>
#include <Fonts/FreeSerif24pt7b.h>

//                   r,r,r,r,r,  g,g, g, g, g, g,   b, b, b, b, b,   h,v
const PinConfig pins(4,5,6,7,8,  9,10,11,12,13,14,  15,16,17,18,21,  1,2);

//VGA Device
VGA vga;
Mode mode = Mode::MODE_320x240x60;
GfxWrapper<VGA> gfx(vga, mode.hRes, mode.vRes);

// Define pins
#define SD_CS_PIN 40   // CD/DAT3 (CS)
#define MOSI_PIN 38    // CMD (MOSI)
#define MISO_PIN 39    // DAT0 (MISO)
#define SCK_PIN 45     // CLK (SCK)

// Create a custom SPI instance
SPIClass mySPI(FSPI);

void setup() {
  delay(5000);
  Serial.begin(115200);

  // Initialize SPI with custom pins
  mySPI.begin(SCK_PIN, MISO_PIN, MOSI_PIN, SD_CS_PIN);

  // Initialize SD card
  if (!SD.begin(SD_CS_PIN, mySPI)) {
    Serial.println("SD Card initialization failed!");
    return;
  }
  Serial.println("SD Card initialized successfully.");

  vga.bufferCount = 2;
	if(!vga.init(pins, mode, 16)) while(1) delay(1);

	vga.start();
  static int x = 0;
	vga.clear(vga.rgb(0x80, 0, 0));
  // List files on the SD card
  File root = SD.open("/");
  printDirectory(root, 0);
}

void loop() {
}

void printDirectory(File dir, int numTabs) {
  while (true) {
    File entry = dir.openNextFile();
    if (!entry) {
      break;
    }
    for (uint8_t i = 0; i < numTabs; i++) {
      Serial.print('\t');
    }
    Serial.print(entry.name());
    vga.clear(vga.rgb(0x80, 0, 0));
    gfx.setCursor(100, 100);
    gfx.print(entry.name());
    vga.show();
    delay(200);
    if (entry.isDirectory()) {
      Serial.println("/");
      printDirectory(entry, numTabs + 1);
    } else {
      Serial.print("\t\t");
      Serial.println(entry.size(), DEC);
    }
    entry.close();
  }
}

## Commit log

2024-10-12 Main 1.0
    [Pick Place for Vesa-Esp(Manufacturing).csv, Pick Place for Vesa-Esp-Backplate(Manufacturing).csv, Top.SchDoc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]
2024-10-20 Review from PCBWAY
    [Pick Place for Vesa-Esp(Manufacturing).csv, Top.SchDoc, VESA-ESP (Manufacturing) BOM.xlsx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]
2024-10-20 BOM modif
    [Top.SchDoc]
2024-10-20 Backplate change and generated
    [Pick Place for Vesa-Esp(Manufacturing).csv, Pick Place for Vesa-Esp-Backplate(Manufacturing).csv, Top.SchDoc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]
2024-10-20 Revision 1.0 submitted to pcbway
    [Top.SchDoc, VESA-ESP-Backplate Layer Stackup.xls, VESA-ESP-Backplate.PrjPcb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]
2025-06-02 Moved folders
    [Pick Place for Vesa-Esp(Manufacturing).csv, Top.SchDoc, VESA-ESP (Manufacturing) BOM.xlsx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]
2025-06-02 Added another folder
    [Pick Place for Vesa-Esp(Manufacturing).csv, Top.SchDoc, VESA-ESP (Manufacturing) BOM.xlsx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]
2025-06-04 Added CP2102 and other small changes...
    [Top.SchDoc, VESA-ESP.PrjPcb]
2025-06-04 Adding and routing
    [Top.SchDoc]
2025-06-04 Adding rules and xsignals
    [Top.SchDoc]
2025-06-07 Added new parts and connections. Also design as well.
    [Top.SchDoc]
2025-06-07 Added new design
    [Top.SchDoc, VESA-ESP.PrjPcb]
2025-06-07 Corrected pcb
    [Top.SchDoc]
2025-06-07 Passing DRC
    [Top.SchDoc, VESA-ESP.PrjPcb]
2025-06-07 Added 0R
    [Top.SchDoc, VESA-ESP.PrjPcb]
2025-06-07 0R NC
    [Top.SchDoc]
2025-06-07 NC compoonent
    [VESA-ESP.PrjPcb]
2025-06-07 Removed manufacturing files
    [Pick Place for Vesa-Esp(Manufacturing).csv, Top.SchDoc, VESA-ESP (Manufacturing) BOM.xlsx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]
2025-06-08 Added release of 1.1
    [Pick Place for Vesa-Esp(Manufacturing).csv, Top.SchDoc, VESA-ESP (Manufacturing) BOM.xlsx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]
2025-06-10 New info on docs
    [Top.SchDoc]
2025-06-30 Added sd card test
    [Top.SchDoc]
2025-07-06 Added new pins
    [Top.SchDoc, VESA-ESP.PrjPcb]
2025-07-06 Added connectors
    [Top.SchDoc]
2025-07-07 Added main files
    [Pick Place for Vesa-Esp.csv, Top.SchDoc, VESA-ESP (Manufacturing) 3D Model.step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]
2025-07-07 New files
    [Vesa-Esp.PcbDoc]
2025-07-25 Adding docs
    [Pick Place for Vesa-Esp.csv, VESA-ESP ([No Variations]) BOM.xlsx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]
2025-07-25 Added dimensions
    [Pick Place for Vesa-Esp.csv, VESA-ESP ([No Variations]) 3D Model.step, VESA-ESP ([No Variations]) BOM.xlsx]
